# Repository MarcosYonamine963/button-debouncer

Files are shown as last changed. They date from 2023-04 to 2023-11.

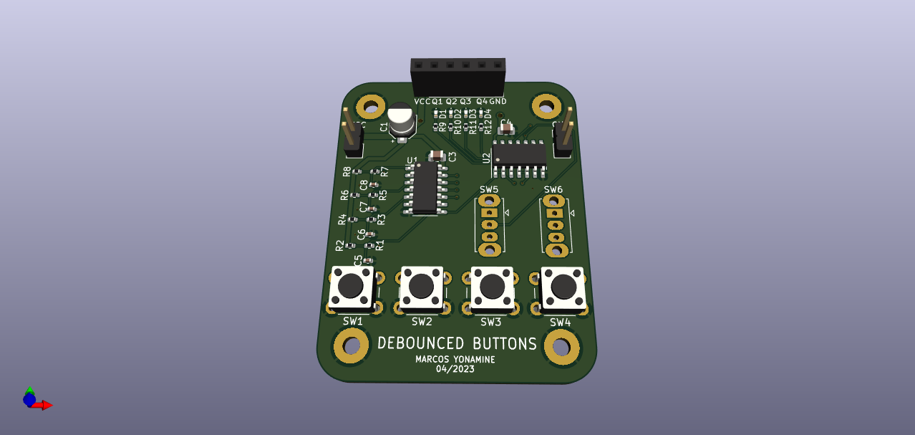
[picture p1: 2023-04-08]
View Files/3D_View2.png

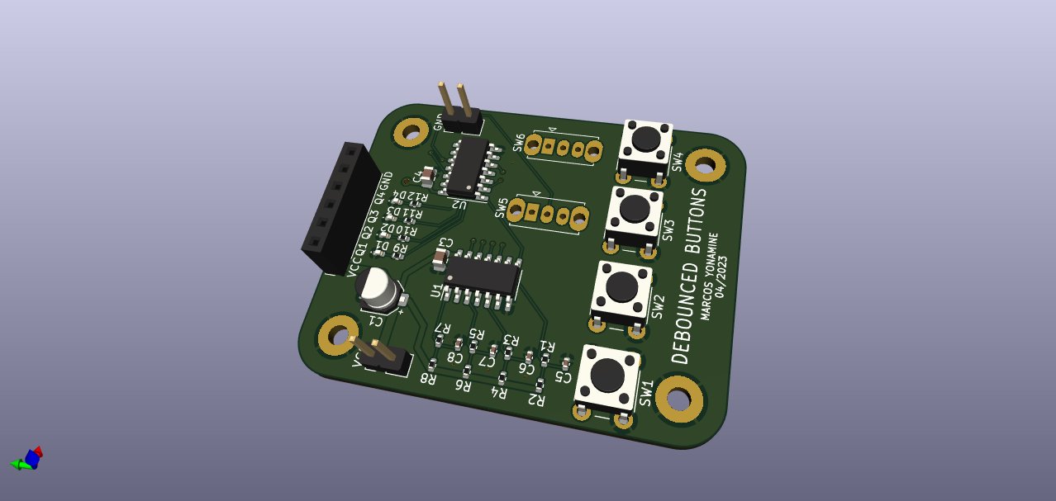
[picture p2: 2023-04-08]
View Files/3D_View.png

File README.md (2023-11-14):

# Four Debounced Buttons

The designed board has four debounced tactile buttons.

The board has an 6-pin socket header, containing the VCC, GND and the four output signals (Q1 to Q4).

Also, there are two auxiliary 2-pin header with VCC and GND, as you can see on the figure below.

3D_View
3D_View2

The logic output of the Buttons 1 and 2 (Q1 and Q2) are NL (normally LOW). For the Buttons 3 and 4, user can configure to NL or NH by the sliding switch (SW5 and SW6).

## Schematics

It was used an quad OR gate to buffer the signal to the LED indicators.

Schematics-1

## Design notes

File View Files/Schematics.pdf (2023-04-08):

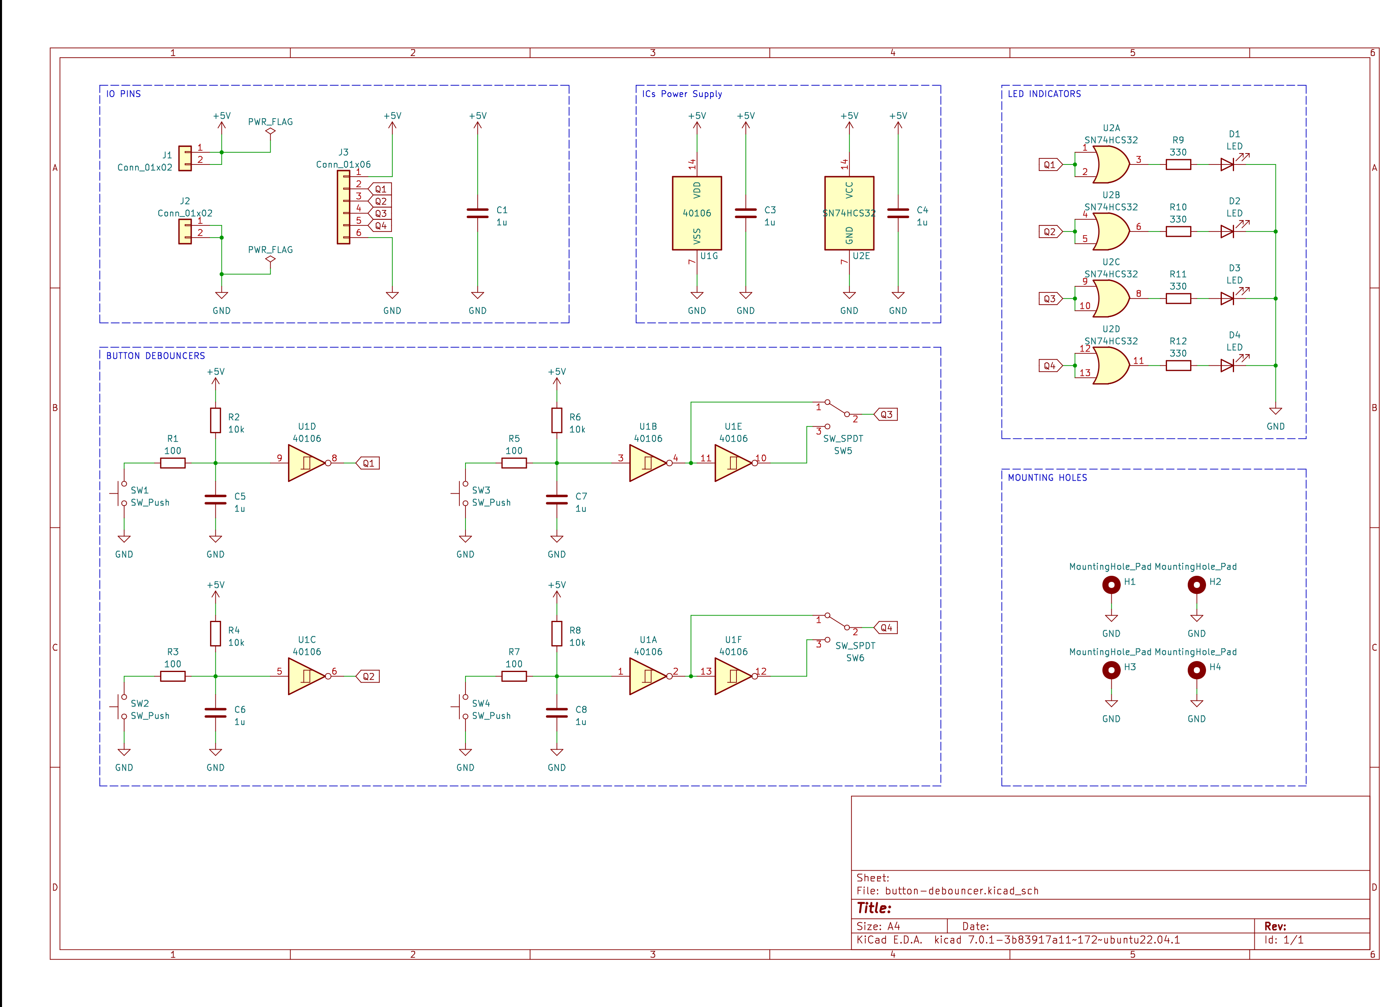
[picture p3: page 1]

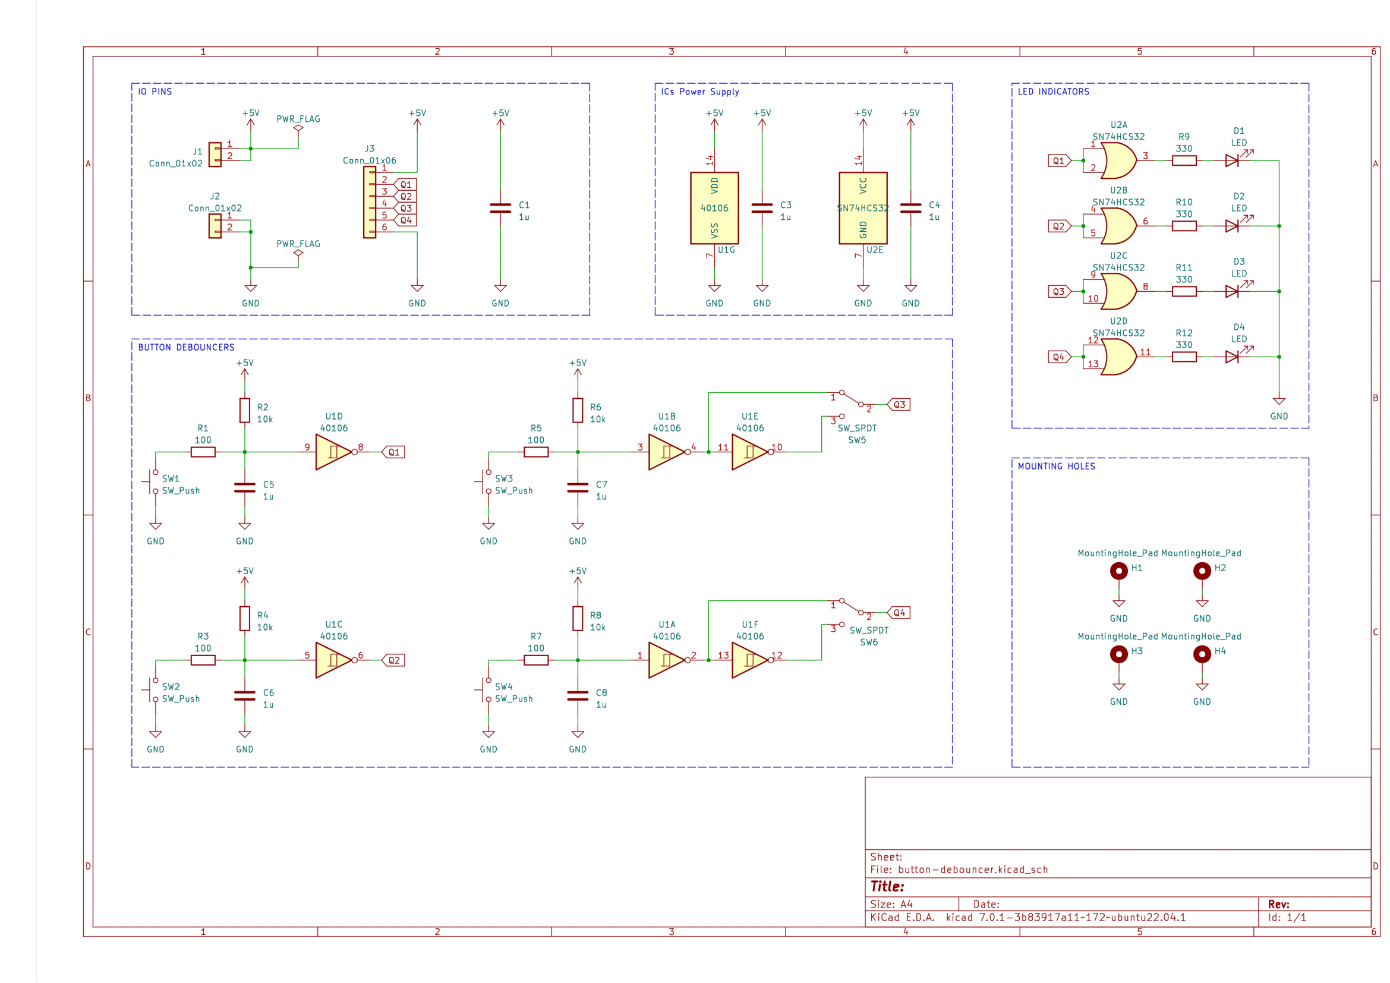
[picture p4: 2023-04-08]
View Files/Schematics-1.png

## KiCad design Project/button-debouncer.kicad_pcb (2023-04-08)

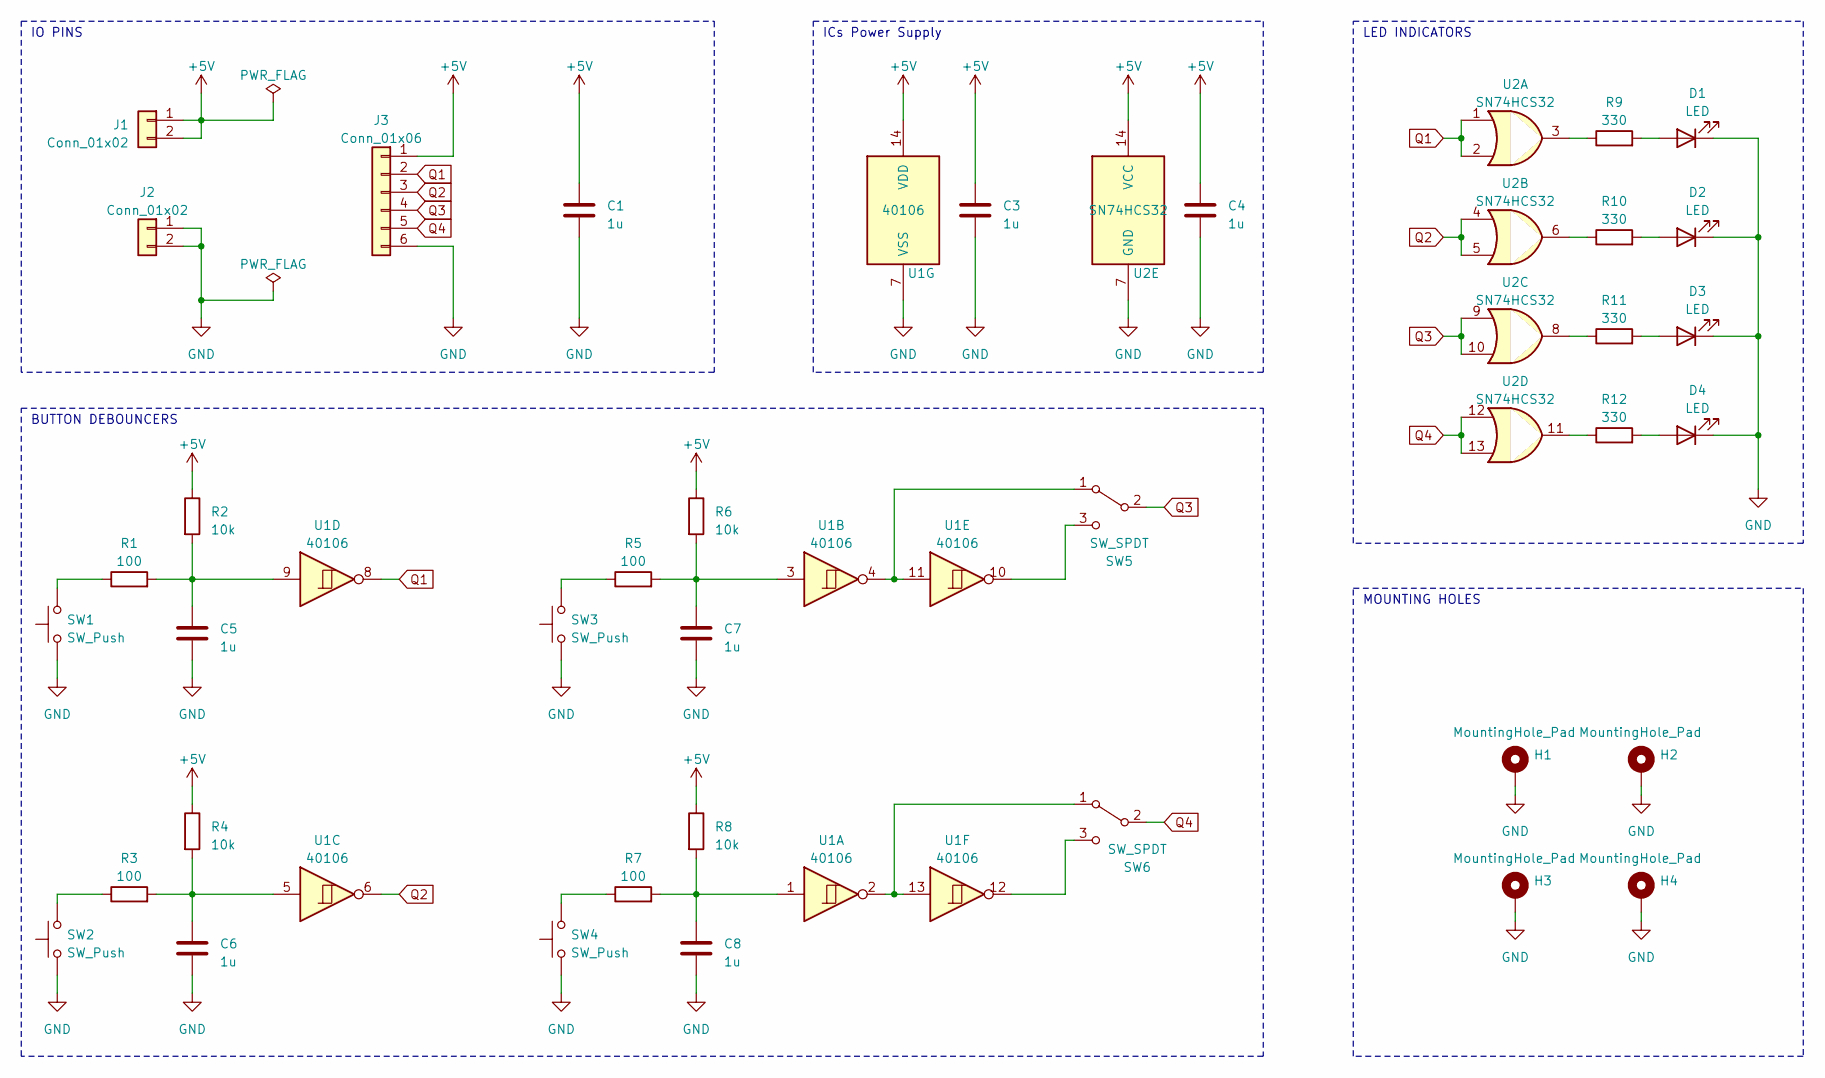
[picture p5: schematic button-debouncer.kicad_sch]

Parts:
C1: 1u; CP_Elec_4x4.5
C3, C4: 1u; C_0805_2012Metric
C5, C6, C7, C8: 1u; C_0402_1005Metric
D1, D2, D3, D4: LED; LED_0402_1005Metric
H1, H2, H3, H4: MountingHole_Pad; MountingHole_2.5mm_Pad
J1, J2: Conn_01x02; PinHeader_1x02_P2.54mm_Vertical
J3: Conn_01x06; PinSocket_1x06_P2.54mm_Vertical
R1, R3, R5, R7: 100; R_0402_1005Metric
R2, R4, R6, R8: 10k; R_0402_1005Metric
R9, R10, R11, R12: 330; R_0402_1005Metric
SW1, SW2, SW3, SW4: SW_Push; SW_PUSH_6mm
SW5, SW6: SW_SPDT; SW_Slide_1P2T_CK_OS102011MS2Q
U1: 40106; SOIC-14_3.9x8.7mm_P1.27mm
U2: SN74HCS32; SOIC-14_3.9x8.7mm_P1.27mm

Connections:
+5V: C1.1, C3.1, C4.1, J1.1, J1.2, J3.1, R2.1, R4.1, R6.1, R8.1, U1.14 (VDD), U2.14 (VCC)
GND: C1.2, C3.2, C4.2, C5.2, C6.2, C7.2, C8.2, D1.1 (K), D2.1 (K), D3.1 (K), D4.1 (K), H1.1, H2.1, H3.1, H4.1, J2.1, J2.2, J3.6, SW1.1, SW2.1, SW3.1, SW4.1, U1.7 (VSS), U2.7 (GND)
unnamed: C5.1, R1.2, R2.2, U1.9
unnamed: C6.1, R3.2, R4.2, U1.5
unnamed: C7.1, R5.2, R6.2, U1.3
unnamed: C8.1, R7.2, R8.2, U1.1
unnamed: D1.2 (A), R9.2
unnamed: D2.2 (A), R10.2
unnamed: D3.2 (A), R11.2
unnamed: D4.2 (A), R12.2
unnamed: R1.1, SW1.2
unnamed: R3.1, SW2.2
unnamed: R5.1, SW3.2
unnamed: R7.1, SW4.2
unnamed: R9.1, U2.3
unnamed: R10.1, U2.6
unnamed: R11.1, U2.8
unnamed: R12.1, U2.11
unnamed: SW5.1 (A), U1.4, U1.11
unnamed: SW5.3 (C), U1.10
unnamed: SW6.1 (A), U1.2, U1.13
unnamed: SW6.3 (C), U1.12
Q1: J3.2, U1.8, U2.1, U2.2
Q2: J3.3, U1.6, U2.4, U2.5
Q3: J3.4, SW5.2 (B), U2.9, U2.10
Q4: J3.5, SW6.2 (B), U2.12, U2.13

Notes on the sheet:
BUTTON DEBOUNCERS
ICs Power Supply
MOUNTING HOLES
IO PINS
LED INDICATORS

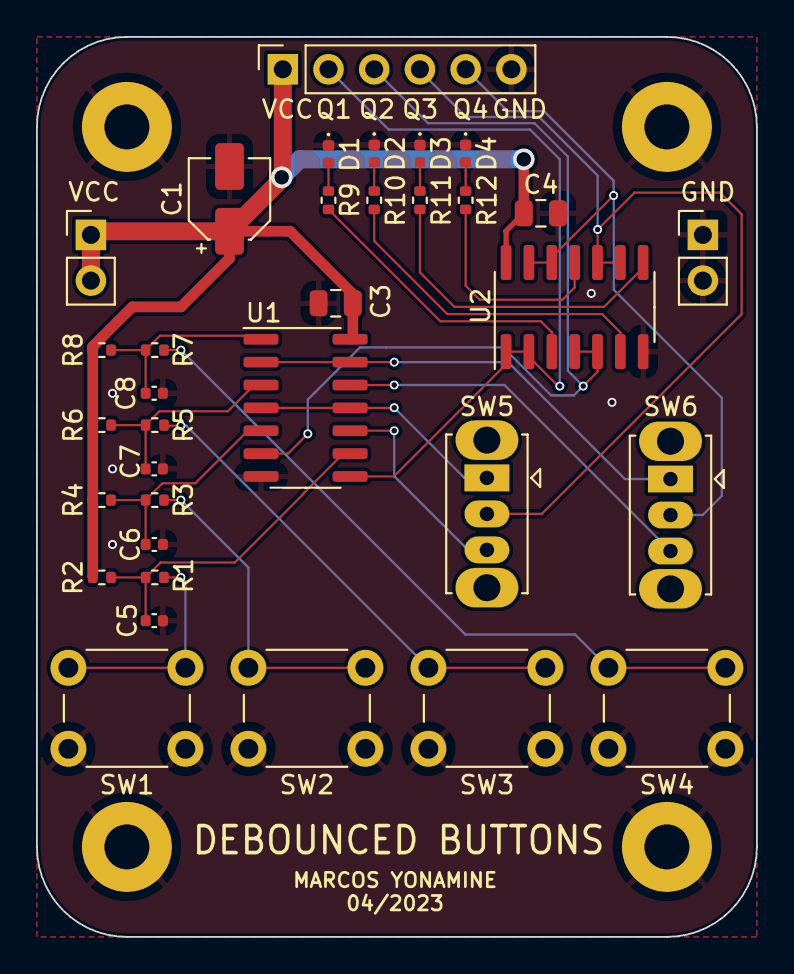
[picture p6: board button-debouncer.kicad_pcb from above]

Board: 2 copper layers, 40.0 x 50.0 mm, 38 parts (0 on the bottom side), 26 nets.

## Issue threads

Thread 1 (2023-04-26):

Clock Generator

MarcosYonamine963, 2023-04-26:
The idea of this new feature is to implement a clock generator on the board.

The board should have a new output pin (clock).

It should have an switch key to select high frequency (about 10 kHz) or low frequency (about 2 Hz). An idea to implement this is with a RC constant with a schmitt-trigger inverter clock, and the switch key select the capacitor. To make a fine adjustment, it should have a trimpot to make the R on RC constant.

MarcosYonamine963, 2023-04-27:
This enhancement will be turned into an other project, with cool features!

Closed 2023-04-27.

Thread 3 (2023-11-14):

Add protections circuits

MarcosYonamine963, 2023-11-14:
- [ ] Add Reverse Polarity protection circuit
- [ ] Add Voltage level protection circuit

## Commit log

2023-04-06 started new blank kiCad project
    [button-debouncer.kicad_pcb, button-debouncer.kicad_sch]
2023-04-06 updated .gitignore file
    [button-debouncer.kicad_pcb, button-debouncer.kicad_sch]
2023-04-06 updated blank project files location
    [button-debouncer.kicad_sch]
2023-04-07 schematics done
    [button-debouncer.kicad_sch]
2023-04-07 fixed power flags
    [button-debouncer.kicad_sch]
2023-04-07 added footprints to components
    [button-debouncer.kicad_sch]
2023-04-07 Finished PCB layout
    [button-debouncer.kicad_pcb]
2023-04-07 updated resistors values
    [button-debouncer.kicad_sch]
2023-04-08 project in stable version - production ordered
    [button-debouncer-B_Cu.gbr, button-debouncer-B_Mask.gbr, button-debouncer-B_Paste.gbr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]
2023-04-08 added schematics in .png file
2023-04-08 updated gerber Drill files
    [button-debouncer-B_Cu.gbr, button-debouncer-B_Mask.gbr, button-debouncer-B_Paste.gbr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]
2023-04-08 generated gerber zip file
    [button-debouncer.kicad_pcb]
